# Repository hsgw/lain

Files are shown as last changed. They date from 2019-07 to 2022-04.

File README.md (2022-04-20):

Build guide for Lain
----------------------------
Lain is ergonomic row staggered 40% keyboard.

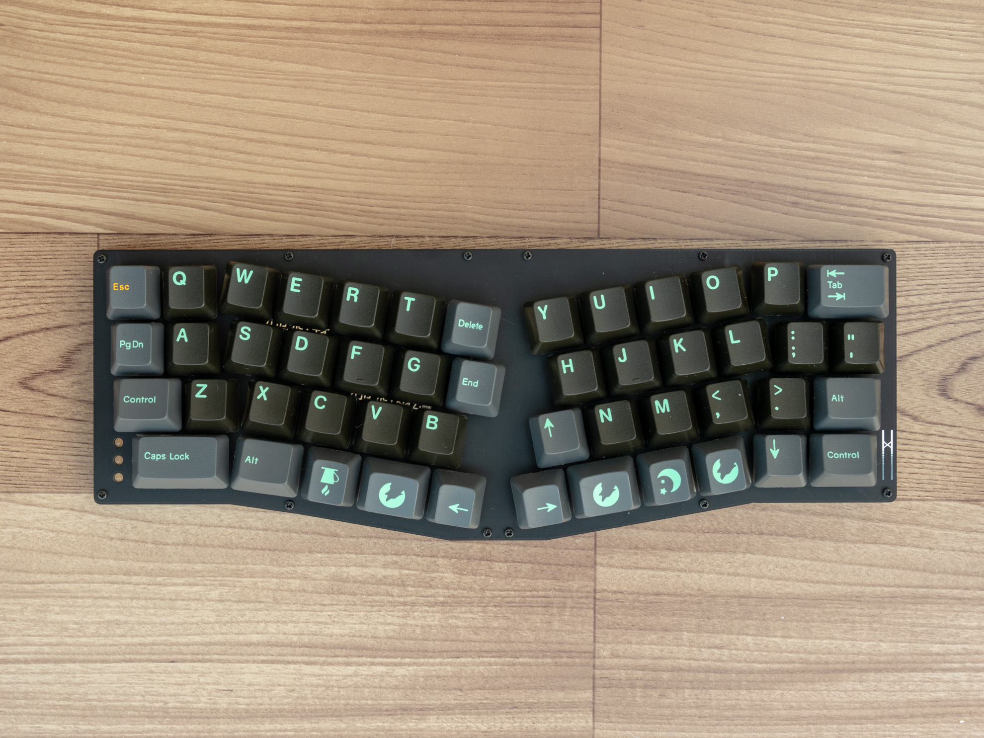
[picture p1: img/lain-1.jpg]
lain


- Cherry MX compatible switch
- kailh hotswap socket
- USB Type-C connector
- PCB mount plate, bottom plate & acrylic sandwitch case
- pre soldered pcb
- lainttl (https://www.nbcuni.co.jp/rondorobe/anime/lain/ttl/)

## Build guide
### Rev.1 (Group buy)
- [Rev.1 日本語](buildguide_rev1_jp.md)
- [Rev.1 English](buildguide_rev1_en.md)

### Rev.Alpha
- [日本語](buildguide_alpha_jp.md)

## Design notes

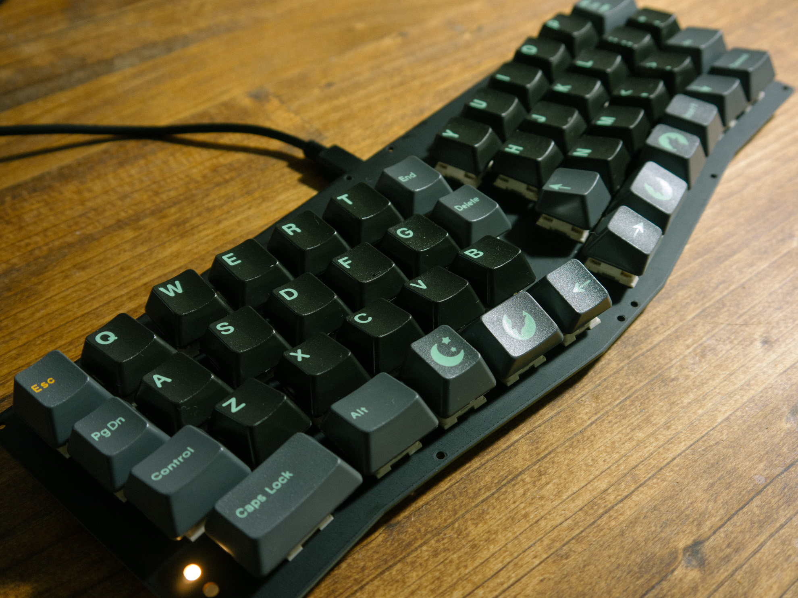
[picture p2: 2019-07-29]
img/alpha/lain-3.jpg

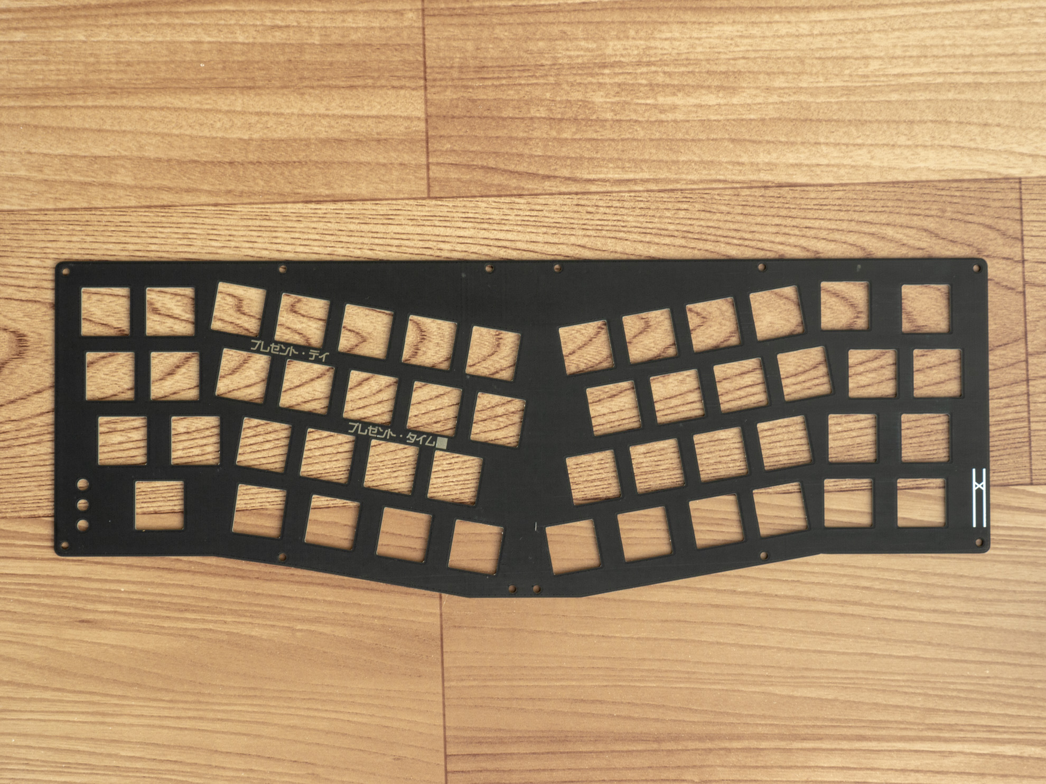
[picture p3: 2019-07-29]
img/alpha/lain_plate.jpg

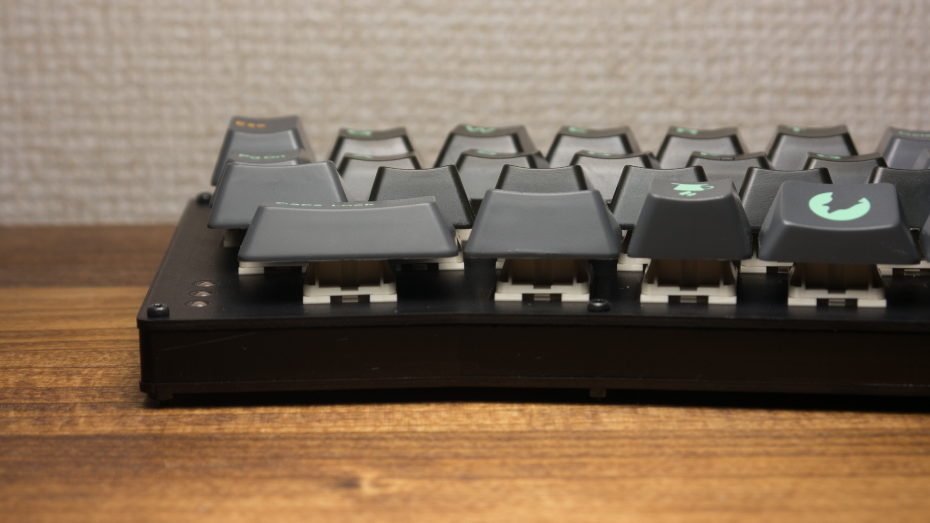
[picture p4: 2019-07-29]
img/alpha/lain-side.jpg

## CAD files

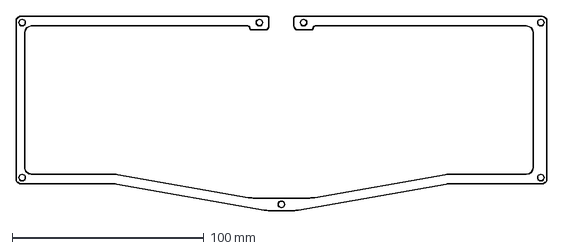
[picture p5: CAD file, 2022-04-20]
lain-rev1-middle.dxf
276.7 x 101.2 mm

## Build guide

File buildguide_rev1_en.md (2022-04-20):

# Lain Rev.1 Build Guide

***Please be sure to read this build guide before assembly***

## Contact
If you have any questions during assembly or missing parts, please contact us at info@5z6p.com

## Parts list
| | Qty | |
|---|---|---|
| main PCB | 1 | Assembled PCB |
| switch plate | 1 | |
| buttom plate | 1 | |
| acrylic middle | 1 | 　　　　　　　　　　　　　　　　　　 　　|
| screws | 1 | M2*4mm screws *14, M2*7mm standsoffs *7 |
| rubber foot | 4 | |
| sticker | 1 | |

## Pre-assembly operation check
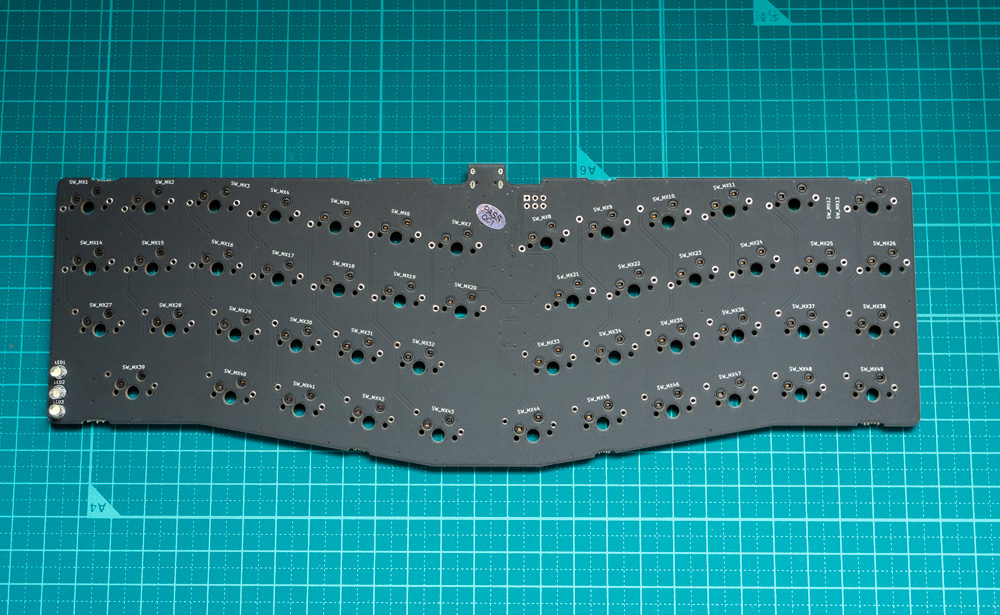
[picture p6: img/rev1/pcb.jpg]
pcb

1. Connect the main PCB to your computer with a USB cable
2. Check operation using Remap
    - [How to Use Remap](how_to_use_remap_en.md)

## Assembly
### Clean acrylic middle part
The acrylic parts are dirty from the polishing process. After removing the protective paper, gently wipe with a soft cloth or paper or rinse with water and dry well.

Due to the manufacturing process, there are scratches on the sides.   
We have removed the scratches after polishing, but if you want to make it perfect, please polish it again with sandpaper or polishing compound.

> See this blog for more information on scratches on acrylic middle part
> https://5z6p.com/2022/02/03/lain-group-buy-update-4/
> 
> I also share the DXF file of acrylic middle part for those who want to remake or customize acrylic parts.   
> Please use this file as well.  
> acrylic middle part dxf file

### Install switches
Install the switch on the main PCB and switch plate.   
To prevent damage to the sockets and switches, the following points should be noted

- ***Keep the legs of the switch in straight***
- ***Do not apply too much force***
- ***Press the socket from the back when inserting the switch***
  
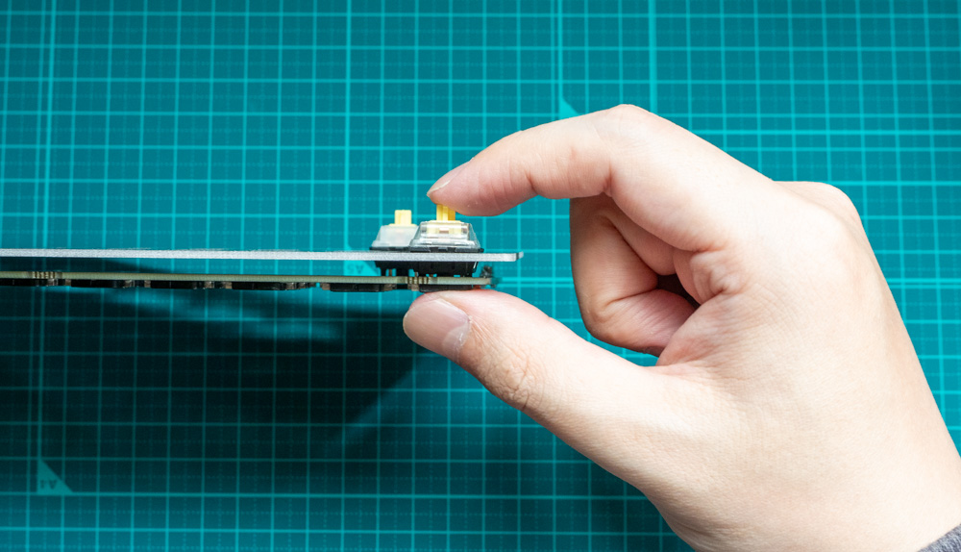
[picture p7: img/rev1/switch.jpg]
switch


### Check operation of switches
Check the operation of the switch with Remap in the same way as the pre-assembly operation check.
- [How to Use Remap](how_to_use_remap_en.md)

### Prepare the bottom case
Attach the spacers to the bottom plate with screws.    
After attaching all the spacers, place the acrylic middle part.   
Acrylic middle part have a specific direction for installation. Please see below photo.

The holes for spacers are small to prevent wobbling.   
If the acrylic middle part does not fit smoothly, install it carefully while gently bending the acrylic middle part.

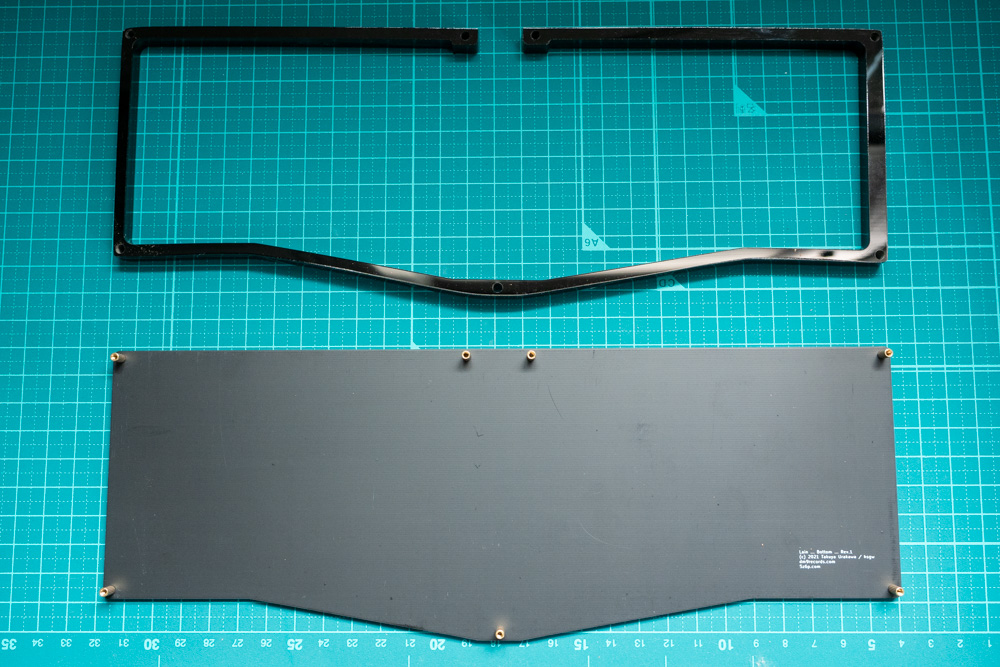
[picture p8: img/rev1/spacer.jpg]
spacer


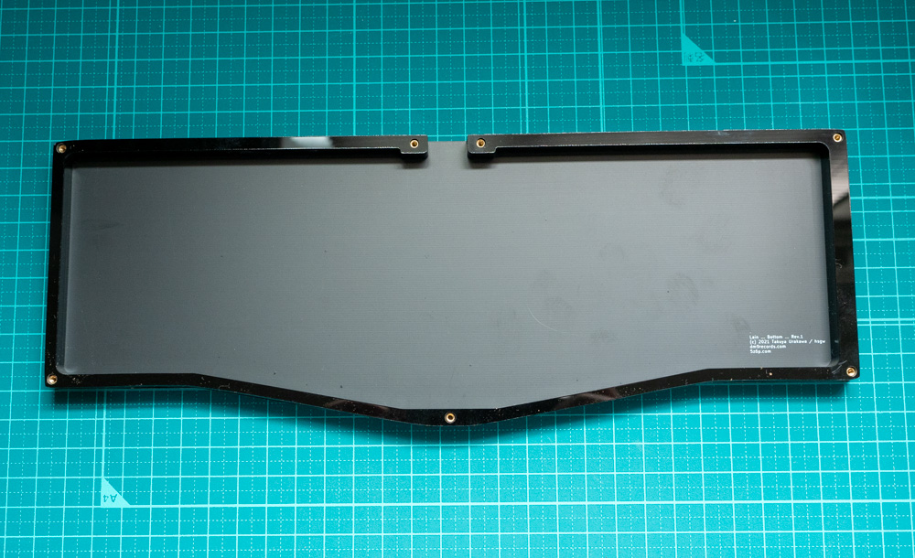
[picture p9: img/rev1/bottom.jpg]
bottom


### Complete
Screw the switch plate + main PCB into the prepared bottom case.
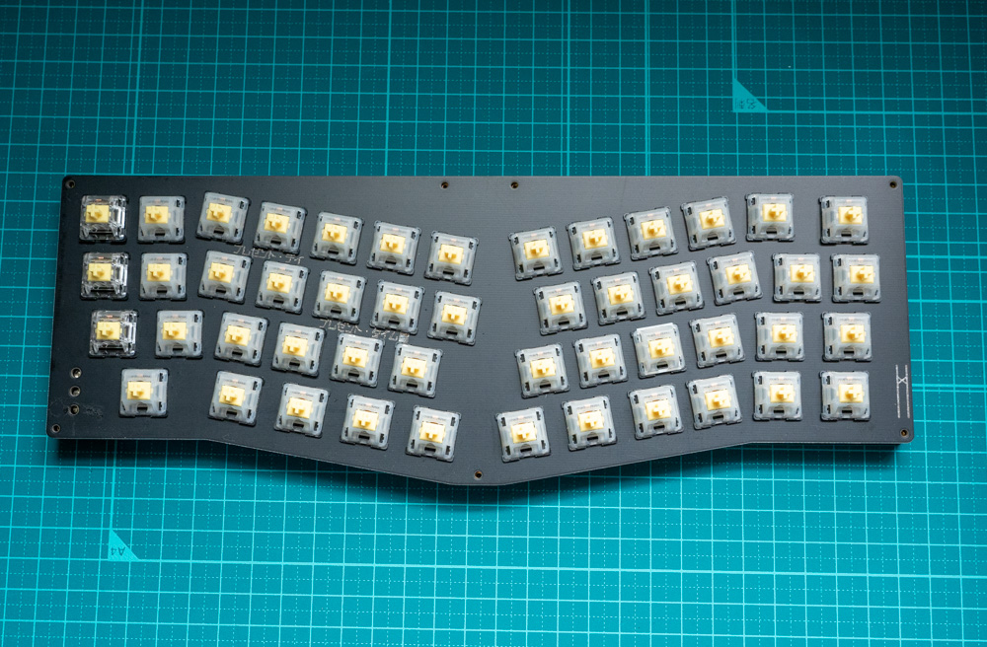
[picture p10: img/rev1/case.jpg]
case


## Replace switches
When replacing a switch, to prevent damage, be sure to remove the bottom plate and insert the new switch while holding the socket.

## Customize keymap
This keyboard is compatible with [Remap](https://remap-keys.app)   
- [How to Use Remap](how_to_use_remap_en.md)  
**Does not compatible with via comfigulator**

## LEDs
The LEDs are set as indicators for `CAPS LOCK`, `LAYER 1`, and `LAYER 2`.   
The firmware must be modified to make the change. 

## Firmware
[QMK Firmware](https://github.com/qmk/qmk_firmware)   
https://github.com/qmk/qmk_firmware/tree/master/keyboards/dm9records/lain

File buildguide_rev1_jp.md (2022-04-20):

# Lain Rev.1 ビルドガイド

***組み立てを始める前に必ず最後まで一通り目を通して下さい***

## 問い合わせ先
キットに対するご質問、部品の不足などはinfo@5z6p.comまでご連絡下さい

## パーツリスト
### キットに含まれるもの
| | 個数 | |
|---|---|---|
| メインPCB | 1 | 実装済みPCB |
| スイッチプレート | 1 | |
| ボトムプレート | 1 | |
| アクリルミドル 　　 | 1 | 　　　　　　　　　　　　　　　　　　 　　|
| ネジ類 | 1 | M2*4mmネジ 14個, M2*7mm スペーサ7個 |
| ゴム足 | 4 | |
| ステッカー | 1 | |

## 組み立て前の動作確認
pcb
1. メインPCBをUSBで接続する
2. Remapを使用して動作確認をする
    - Remapの使い方は[こちら](how_to_use_remap_jp.md)

## 組み立て
### アクリルパーツを綺麗にする
アクリルパーツには研磨時の汚れが残っています。保護紙を剥がしたあと優しく柔らかい布や紙でふくか水洗いしてよく水気を拭き取って下さい。

製造の都合上、側面に傷がついています。   
研磨後にひどいものは取り除いていますが、完璧な状態にする場合は紙やすりや研磨剤で磨き直して下さい。

> アクリルミドルパーツの傷についてはこちらのブログを参照して下さい。
> https://5z6p.com/2022/02/03/lain-group-buy-update-4/
>
> また、アクリルパーツを作り直したい方、カスタマイズしたい方向けにアクリルミドルパーツのDXFファイルを用意しています。   
> こちらもご利用下さい。
> アクリルミドルパーツのDXFデータ

### スイッチを取り付ける
メインPCBとスイッチプレートにスイッチをとりつけます。   
ソケットやスイッチの破壊を防止するために注意する点は以下のとおりです。

- ***スイッチの足をまっすぐに整える***
- ***無理に力をかけない***
- ***スイッチを差し込むときはソケットを裏から押さえる***
  
switch

### スイッチの動作確認
組み立て前の動作確認と同じようにしてスイッチが動作するか、Remapで確認します。   
Remapの使い方は[こちら](how_to_use_remap_jp.md)。

### ケースの準備
ボトムプレートにスペーサをねじで取り付けます。    
全てのスペーサを取り付けたあと、アクリルミドルパーツを重ねます。   
アクリルミドルパーツには方向があるので注意して下さい。

がたつきを防ぐために、スペーサの穴が小さめになっています。   
スムーズに入らない場合はアクリルミドルパーツを優しく曲げながら注意深く取り付けて下さい。

spacer

bottom

### 完成
スイッチプレート+メインPCBを準備したケースにネジ止めします。
case

## スイッチの交換について
スイッチを交換する場合は、破損を防ぐためにボトムプレートを取り外してソケットを押さえながら新しいスイッチを差し込んで下さい。

## キーマップのカスタマイズ
[Remap](https://remap-keys.app)に対応しています。   
使い方は[こちら](how_to_use_remap_jp.md)   
**via configulatorには対応していません**

## LEDについて
LEDは、`CAPS LOCK`, `LAYER 1`, `LAYER 2` のインジケータとして設定されています。   
変更する場合はファームウェアを書き換える必要があります。

## ファームウェア
[QMK Firmware](https://github.com/qmk/qmk_firmware)にマージされています。   
https://github.com/qmk/qmk_firmware/tree/master/keyboards/dm9records/lain

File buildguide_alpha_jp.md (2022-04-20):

# Lain Rev.Alpha ビルドガイド

***組み立てを始める前に必ず最後まで一通り目を通して下さい***

## パーツリスト
### キットに含まれるもの
| | 個数 | |
|---|---|---|
| メインPCB | 1 | 実装済みPCB |
| プレートPCB | 1 | |
| ボトムPCB | 1 | |
| アクリルパーツ(右) | 1 | アクリルパーツは左右異なる物が1ペア |
| アクリルパーツ(左) | 1 | |
| ネジ類 | 1 | M2*14mm 12個、M2ナット12個 |
| ゴム足 | 4 | |

### その他必要なもの
- Cherry MX互換スイッチ 49個
- キーキャップ
  - 一般的な101英語キーボード用のもので一通り揃います
- USB type-cケーブル

## レイアウト
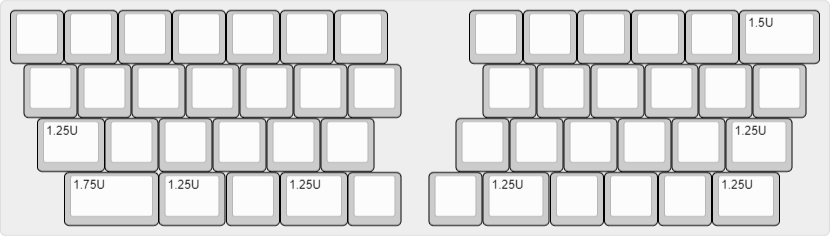
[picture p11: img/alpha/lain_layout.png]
layout


## 組み立て
### メインPCBの動作確認
組立前にメインPCBの動作確認をします。   
メインPCBにはデフォルトのファームウェアが予め書き込まれています。   
USBケーブルでPCと接続し正しく認識されているか、適当なジャンパー線などでソケットのパッドをショートさせて文字が入力されるか確認して下さい。

また、目視でソケット、USBコネクタのはんだづけを確認して下さい。   

### プレートとスイッチの取り付け
プレートにスイッチを1つはめ込み、メインPCBへ差し込みます。   
このとき、***スイッチのピンが曲がっていないこと***、***スイッチの方向*** を必ず確認して下さい。   
無理に取り付けた場合ソケットがメインPCBから剥がれてしまいます。

端のスイッチから対角になるよう順番に取り付けていきます。

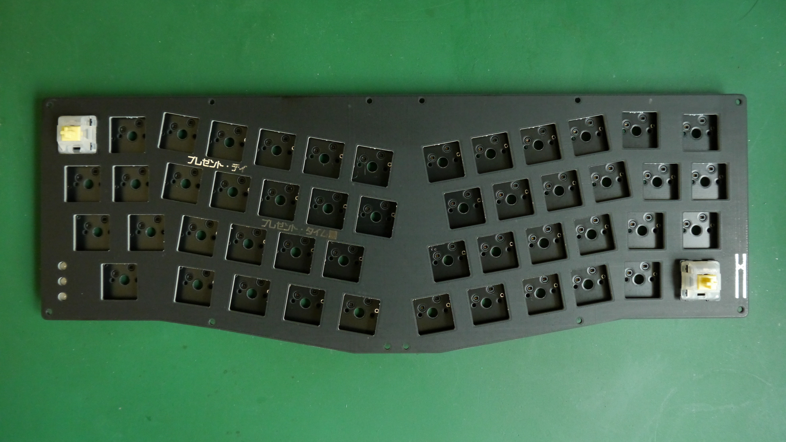
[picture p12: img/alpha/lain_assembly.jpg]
plate


### スイッチの動作確認
すべてのスイッチが正しく動作するかPCに接続して確認して下さい。

### ケースの組み立て
アクリルの保護紙を剥がしてキーボードにネジ止めします。   
アクリルパーツには左右があります。   
手前側の曲がっている部分で見分けることができます。   

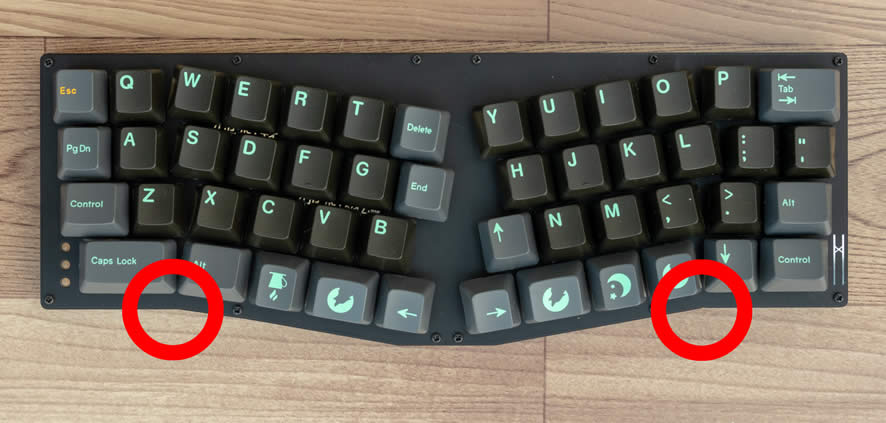
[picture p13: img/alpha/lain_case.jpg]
case


基板の側面を黒油性ペンで塗ると基板の端面が目立ちません。

## ファームウェア
QMK Firmwareに対応しています。   
公式のリポジトリにはまだmergeされていないため、以下のURLよりcloneして下さい。   
https://github.com/hsgw/qmk_firmware/tree/lain

### 書き込み方法
#### ブートローダへの入り方
ファームウェアを書き込む際にはあらかじめキーボードをブートローダモードにしておく必要があります。   
以下のどちらかの方法でブートローダへ入りファームウェアの書き換えが可能になります。
1. QMK Firmwareの```RESET```キーコードを押す
    - Defaultのファームウェアであればレイヤー切り替えキーを2つとも同時押しして左上端のキーを押す
      (https://github.com/hsgw/qmk_firmware/blob/lain/keyboards/lain/keymaps/default/keymap.c#L49)
2. 基板上のタクトスイッチを使う
    1. Resetスイッチを押す
    2. Bootスイッチを押す
    3. Resetスイッチを離す
    4. Bootスイッチを離す

#### (windowsの場合)ドライバを入れ替える
Zadigを使用してOS標準で入るドライバをWinUSBのものに入れ替える必要があります。
1. zadigをダウンロード、解凍する。(https://zadig.akeo.ie/)
2. キーボードをbootloaderモードでPCに接続する   
(この段階では```STM Device in DFU Mode```として認識されているはず)
3. zadigを起動して```Options → List All devices```にチェック
4. ```STM Device in DFU Mode```もしくは```STM32 BOOTLOADER```を選択して、```WinUSB```をインストールする   
**書き換えるデバイス名を必ず確認してから```Replace Driver```を押して下さい。**   
**間違えたデバイスのドライバを書き換えると最悪PCが操作不能になります**

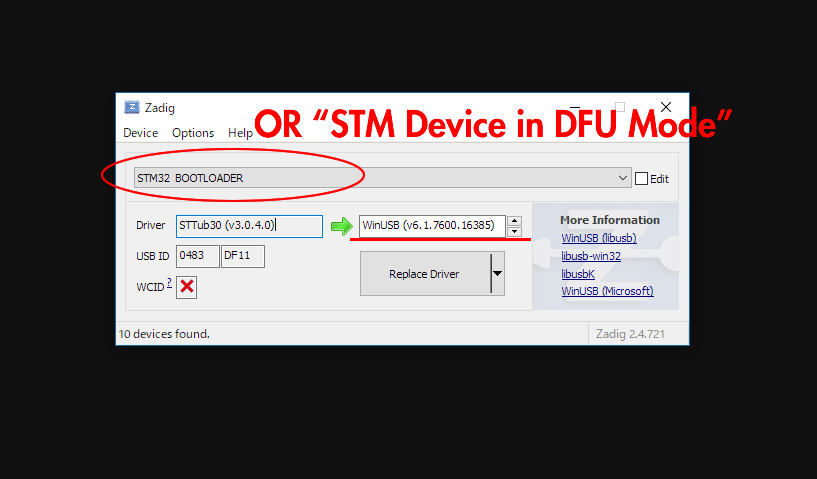
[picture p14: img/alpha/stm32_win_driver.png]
zadig

5. 再度キーボードをbootloaderモードでPCに接続。   
(```STM32 BOOTLOADER```として認識されていればOK)

### ファームウェアのビルドと書き込み
キーボードを```ブートローダモード```にしてから
```
make lain:default:dfu-util
```

### 問い合わせ先
パーツの不足、不具合、ご質問は以下へお願いします。

info@5z6p.com

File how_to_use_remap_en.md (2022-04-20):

# How to use Remap
Remap(https://remap-keys.app/) is an application for customize your keyboard keymap from web browser. 

## Recognize keyboard
1. Connect keyboard and PC with USB cable
2. Open https://remap-keys.app/
3. Click `START REMAP FOR YOUR KEYBOARD`
4. Click `+ KEYBOARD`
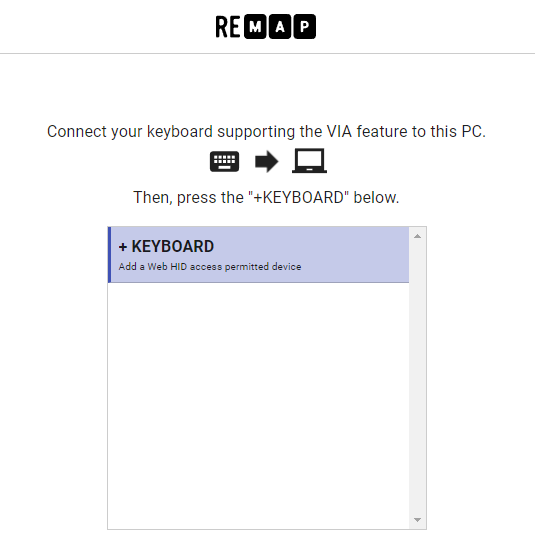
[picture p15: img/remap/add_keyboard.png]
add keyboard
   
5. Select keyboard from list
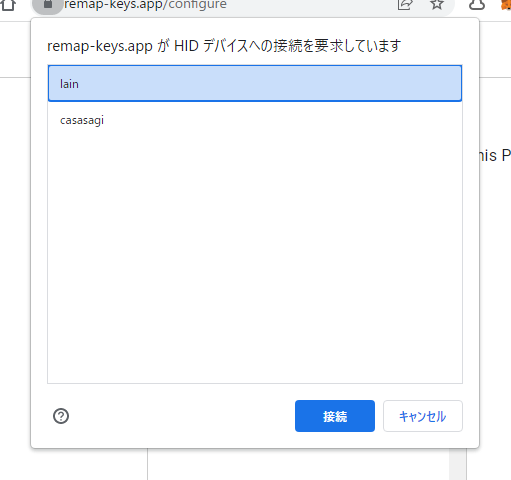
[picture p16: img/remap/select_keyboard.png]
select keyboard
   
6. After recognized, keymap is displayed
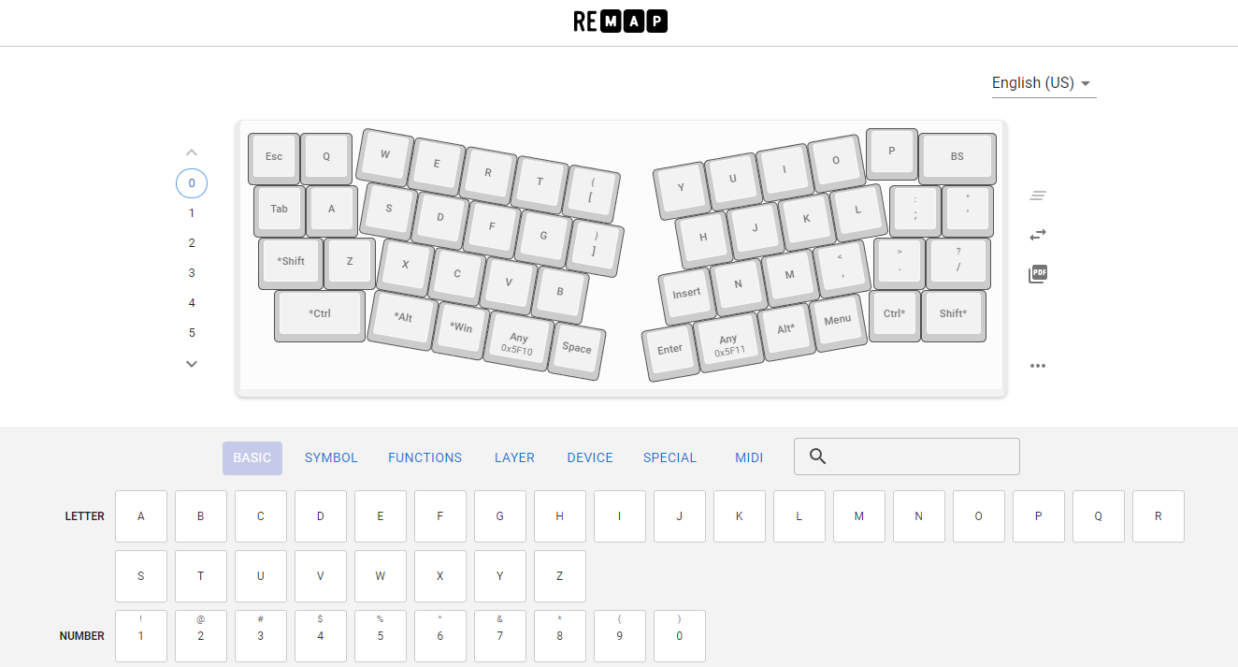
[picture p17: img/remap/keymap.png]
keymap
   

## Customize keymap
Drag and drop from list to keymap or click keymap

To write it to the keyboard, click `flash`

## Test keyboard
1. Connect keyboard to remap
2. Select `Test Matirx Mode` from the menu in the lower right corner of the keymap view
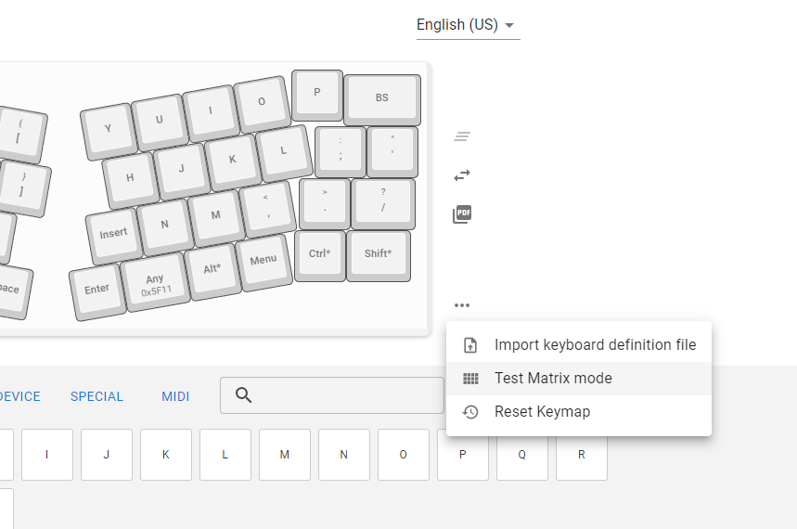
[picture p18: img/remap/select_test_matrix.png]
enter test matrix mode
   
3. When a key is pressed, the color of key changes
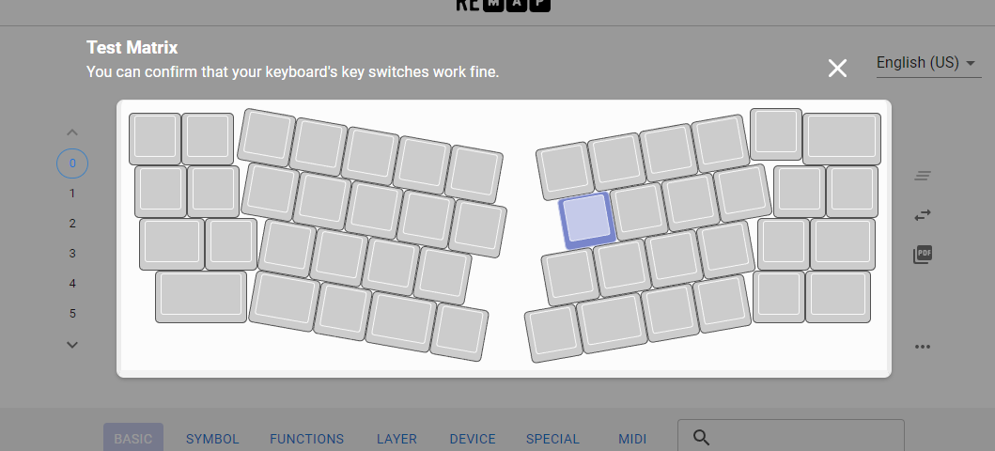
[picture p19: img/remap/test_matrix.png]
test matrix mode


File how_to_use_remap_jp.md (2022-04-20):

# Remapの使い方
Remap(https://remap-keys.app/)はブラウザからキーボードのキーマップを変更するためのアプリケーションです。

## キーボードを認識させるまで
1. キーボードとPCをUSBケーブルで接続する
2. https://remap-keys.app/ を開く
3. `START REMAP FOR YOUR KEYBOARD` をクリック
4. `+ KEYBOARD` をクリック
   add keyboard
5. 一覧からキーボードを選択
   select keyboard
6. 成功するとキーマップが表示される
   keymap

## キーマップの書き換え
キーボードが接続中なら、ドラッグアンドドロップやキーをクリックするとキーマップを変更できます。
キーボードに書き込むには、`flash` をクリックします。

## キーボードの動作確認
1. キーボードをRemapに接続する
2. キーマップ表示部のメニューから `Test Matirx Mode` を選択する
   enter test matrix mode
3. 入力のあったキーの色が変わる
   test matrix mode

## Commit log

2019-08-11 add document for driver on windows
2022-04-20 add tips for replace switches
2022-04-20 add dxf file
    [lain-rev1-middle.dxf]
